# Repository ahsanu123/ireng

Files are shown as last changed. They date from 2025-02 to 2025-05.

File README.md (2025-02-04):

<p>
  <a href="">
    
  </a>
  <a href="">
    
  </a>
  <a href="">
    
  </a>
  <a href="https://github.com/ahsanu123/ireng/blob/main/LICENSE">
    
  </a>
</p>

<p align="center">
   <br/>
</p>

# ✒️ Introduction 

Ireng is custom Black Magic Probe Based on STM32F103RCT. Only for fun 😙 and learning about debugging in microcontroller.

<details>
  <summary>expands me!!</summary>
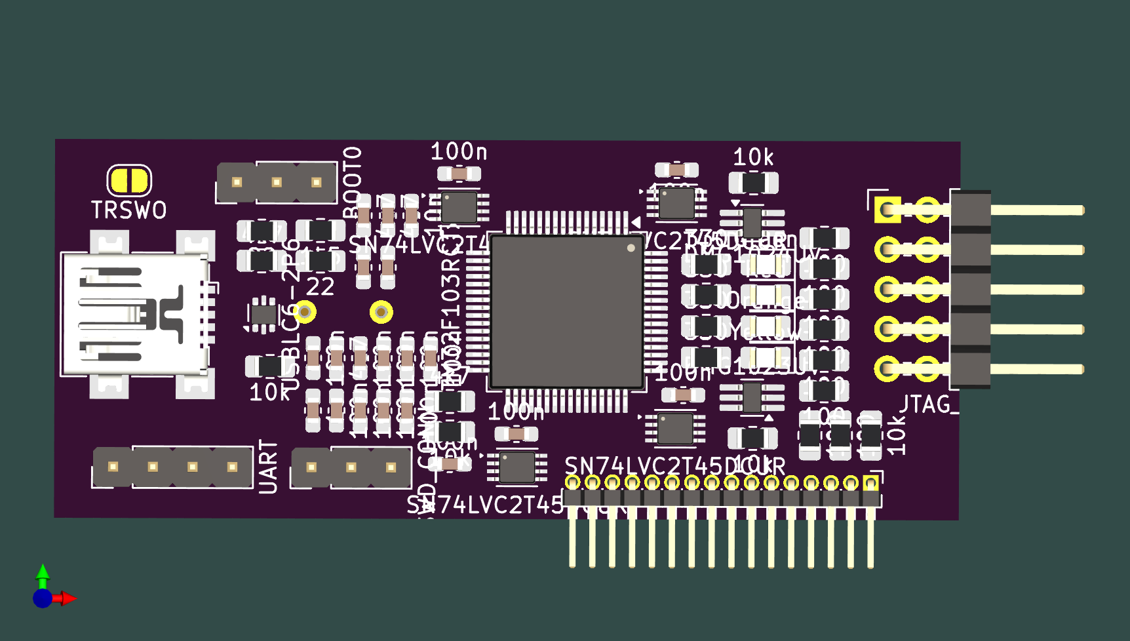
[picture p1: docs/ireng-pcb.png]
     <br/>
</details>

## 🌳 TODO LOG

- ~~Add SPI Flash from windbond, jumat 17 januari 2025 at 19:51~~, no pin left for spi and dont want to change pinout of original schematic.
- ~~re-check schematic,  jumat 17 januari 2025 at 19:51~~
- add usb type c, and use usb micro b as backup,  jumat 17 januari 2025 at 19:51

## 🧱 Reference 

- [Black Magic Probe Book](https://www.compuphase.com/electronics/BlackMagicProbe.pdf)
- [STM32F10xxx Getting Started Hardware Development](https://www.st.com/resource/en/application_note/an2586-getting-started-with-stm32f10xxx-hardware-development-stmicroelectronics.pdf)

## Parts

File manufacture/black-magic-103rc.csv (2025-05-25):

Reference | Value | Datasheet | Footprint | Qty | DNP
C1,C3,C9 | 4u7 | ~ | Capacitor_SMD:C_0603_1608Metric_Pad1.08x0.95mm_HandSolder | 3
C2 | 10n | ~ | Capacitor_SMD:C_0603_1608Metric_Pad1.08x0.95mm_HandSolder | 1
C4,C5,C6,C7,C8,C11,C12,C13,C14,C15,C16,C17,C18,C19,C22 | 100n | ~ | Capacitor_SMD:C_0603_1608Metric_Pad1.08x0.95mm_HandSolder | 15
C10 | 1u | ~ | Capacitor_SMD:C_0603_1608Metric_Pad1.08x0.95mm_HandSolder | 1
C20,C21 | 20p | ~ | Capacitor_SMD:C_0603_1608Metric_Pad1.08x0.95mm_HandSolder | 2
D1 | Green | ~ | LED_SMD:LED_0805_2012Metric_Pad1.15x1.40mm_HandSolder | 1
D2 | Red | ~ | LED_SMD:LED_0805_2012Metric_Pad1.15x1.40mm_HandSolder | 1
D3 | Orange | ~ | LED_SMD:LED_0805_2012Metric_Pad1.15x1.40mm_HandSolder | 1
D4 | Yellow | ~ | LED_SMD:LED_0805_2012Metric_Pad1.15x1.40mm_HandSolder | 1
J1 | USB_B_Micro | ~ | Connector_USB:USB_Mini-B_Wuerth_65100516121_Horizontal | 1
J2 | JTAG_SWD_10 | http://infocenter.arm.com/help/topic/com.arm.doc.ddi0314h/DDI0314H_coresight_components_trm.pdf | Connector_PinHeader_2.54mm:PinHeader_2x05_P2.54mm_Horizontal | 1
J3 | UART | ~ | Connector_PinHeader_2.54mm:PinHeader_1x04_P2.54mm_Vertical | 1
J4 | SWD_CONN | ~ | Connector_PinHeader_2.54mm:PinHeader_1x03_P2.54mm_Vertical | 1
J5 | BOOT0 | ~ | Connector_PinHeader_2.54mm:PinHeader_1x03_P2.54mm_Vertical | 1
J6 | PORTC | ~ | Connector_PinHeader_1.27mm:PinHeader_1x16_P1.27mm_Horizontal | 1
P1 | USB_C_Plug_USB2.0 | https://www.usb.org/sites/default/files/documents/usb_type-c.zip | Connector_USB:USB_C_Receptacle_GCT_USB4110 | 1
Q1 | DMG1024UV | ~ | Package_TO_SOT_SMD:SOT-363_SC-70-6_Handsoldering | 1
Q2 | DMG1023UV | ~ | Package_TO_SOT_SMD:SOT-363_SC-70-6_Handsoldering | 1
R1,R2,R3,R4,R15,R16,R17,R18 | 100 | ~ | Resistor_SMD:R_0805_2012Metric_Pad1.20x1.40mm_HandSolder | 8
R5,R12 | 4k7 | ~ | Resistor_SMD:R_0805_2012Metric_Pad1.20x1.40mm_HandSolder | 2
R6,R7,R8,R13,R14 | 10k | ~ | Resistor_SMD:R_0805_2012Metric_Pad1.20x1.40mm_HandSolder | 5
R9,R10 | 22 | ~ | Resistor_SMD:R_0805_2012Metric_Pad1.20x1.40mm_HandSolder | 2
R11 | 1k5 | ~ | Resistor_SMD:R_0805_2012Metric_Pad1.20x1.40mm_HandSolder | 1
R19,R20,R21,R22 | 330 | ~ | Resistor_SMD:R_0805_2012Metric_Pad1.20x1.40mm_HandSolder | 4
R23,R24 | 5k1 | ~ | Resistor_SMD:R_0805_2012Metric_Pad1.20x1.40mm_HandSolder | 2
SW1 | SW_SPST | ~ | Button_Switch_SMD:SW_Push_1P1T_NO_6x6mm_H9.5mm | 1
U1 | USBLC6-2P6 | https://www.st.com/resource/en/datasheet/usblc6-2.pdf | Package_TO_SOT_SMD:SOT-666 | 1
U2,U5,U6,U7 | SN74LVC2T45DCUR | http://www.ti.com/lit/ds/symlink/sn74lvc2t45.pdf | Package_SO:VSSOP-8_2.4x2.1mm_P0.5mm | 4
U3 | STM32F103RCTx | https://www.st.com/resource/en/datasheet/stm32f103rc.pdf | Package_QFP:LQFP-64_10x10mm_P0.5mm | 1
U4 | AMS1117-3.3 | http://www.advanced-monolithic.com/pdf/ds1117.pdf | Package_TO_SOT_SMD:SOT-223-3_TabPin2 | 1
Y2 | 8Mhz | ~ | Crystal:Crystal_HC18-U_Vertical | 1

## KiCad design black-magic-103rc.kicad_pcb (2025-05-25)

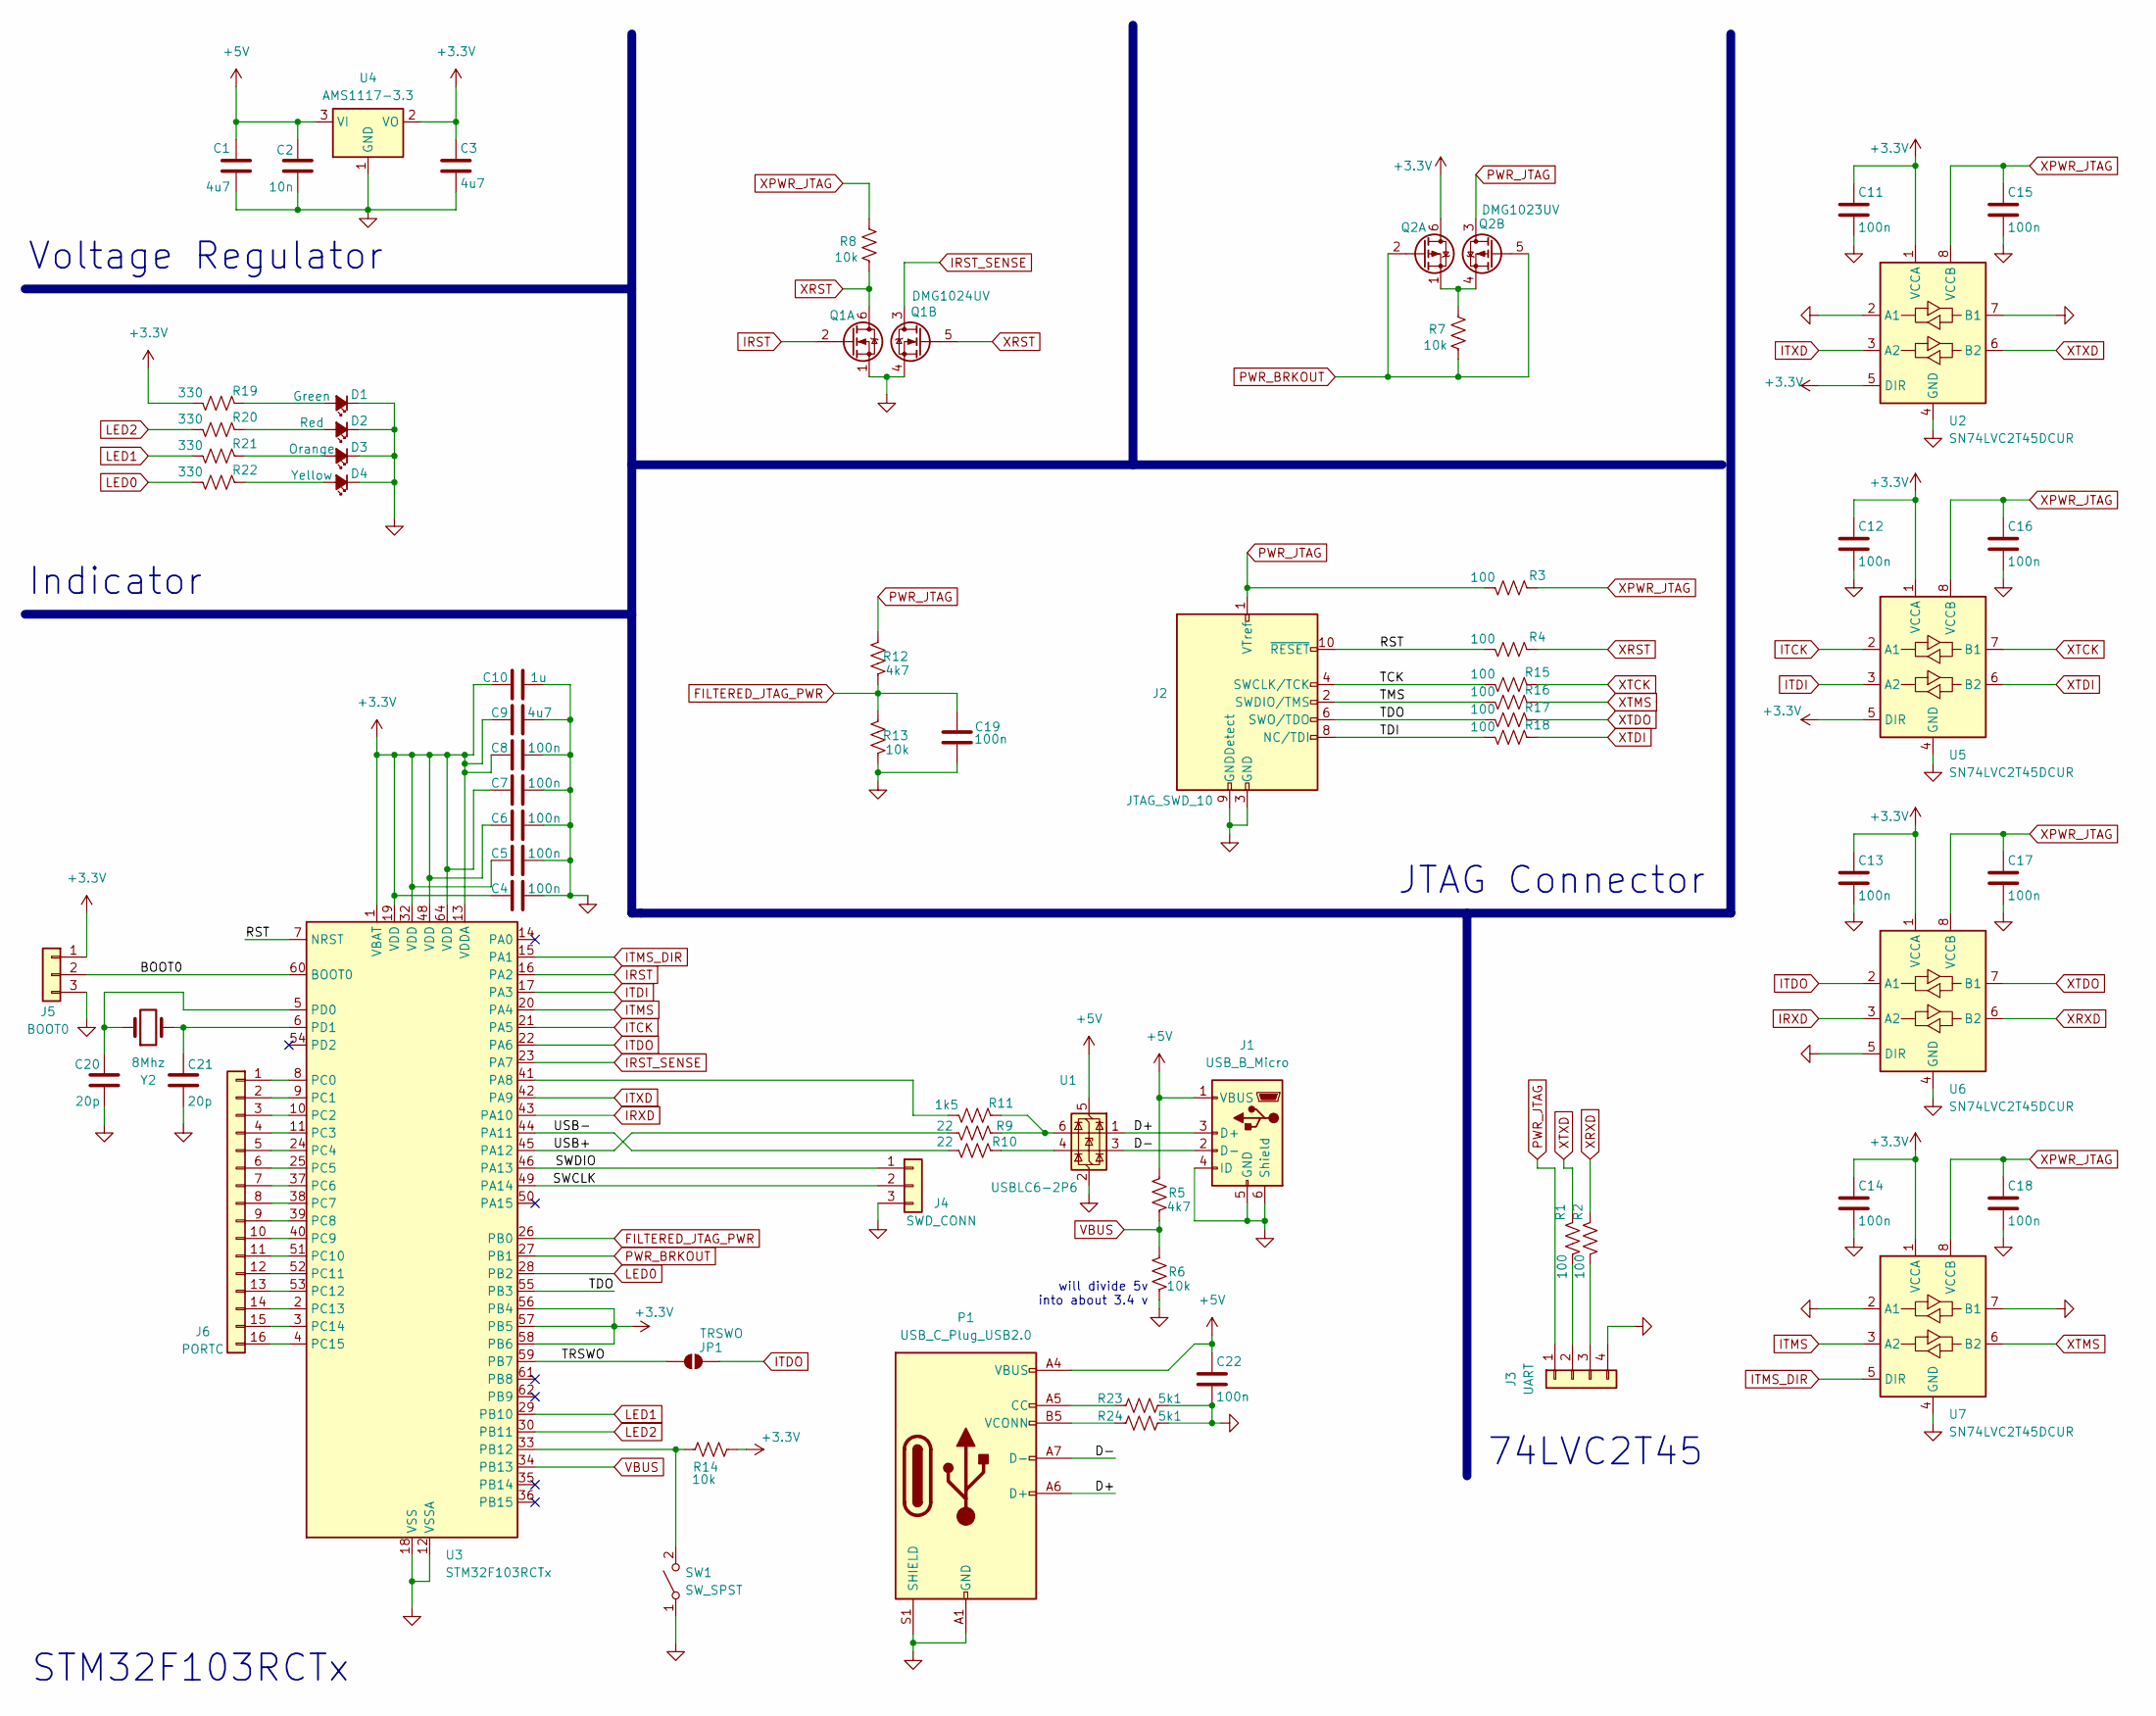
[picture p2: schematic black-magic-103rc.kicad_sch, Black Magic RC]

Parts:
C1, C3, C9: 4u7; C_0603_1608Metric_Pad1.08x0.95mm_HandSolder
C2: 10n; C_0603_1608Metric_Pad1.08x0.95mm_HandSolder
C4, C5, C6, C7, C8, C11, C12, C13, C14, C15, C16, C17, C18, C19, C22: 100n; C_0603_1608Metric_Pad1.08x0.95mm_HandSolder
C10: 1u; C_0603_1608Metric_Pad1.08x0.95mm_HandSolder
C20, C21: 20p; C_0603_1608Metric_Pad1.08x0.95mm_HandSolder
D1: Green; LED_0805_2012Metric_Pad1.15x1.40mm_HandSolder
D2: Red; LED_0805_2012Metric_Pad1.15x1.40mm_HandSolder
D3: Orange; LED_0805_2012Metric_Pad1.15x1.40mm_HandSolder
D4: Yellow; LED_0805_2012Metric_Pad1.15x1.40mm_HandSolder
J1: USB_B_Micro; USB_Mini-B_Wuerth_65100516121_Horizontal
J2: JTAG_SWD_10; PinHeader_2x05_P2.54mm_Horizontal
J3: UART; PinHeader_1x04_P2.54mm_Vertical
J4: SWD_CONN; PinHeader_1x03_P2.54mm_Vertical
J5: BOOT0; PinHeader_1x03_P2.54mm_Vertical
J6: PORTC; PinHeader_1x16_P1.27mm_Horizontal
JP1: TRSWO; SolderJumper-2_P1.3mm_Open_RoundedPad1.0x1.5mm
P1: USB_C_Plug_USB2.0; USB_C_Receptacle_GCT_USB4110
Q1: DMG1024UV; SOT-563
Q2: DMG1023UV; SOT-563
R1, R2, R3, R4, R15, R16, R17, R18: 100; R_0805_2012Metric_Pad1.20x1.40mm_HandSolder
R5, R12: 4k7; R_0805_2012Metric_Pad1.20x1.40mm_HandSolder
R6, R7, R8, R13, R14: 10k; R_0805_2012Metric_Pad1.20x1.40mm_HandSolder
R9, R10: 22; R_0805_2012Metric_Pad1.20x1.40mm_HandSolder
R11: 1k5; R_0805_2012Metric_Pad1.20x1.40mm_HandSolder
R19, R20, R21, R22: 330; R_0805_2012Metric_Pad1.20x1.40mm_HandSolder
R23, R24: 5k1; R_0805_2012Metric_Pad1.20x1.40mm_HandSolder
SW1: SW_SPST; SW_Push_1P1T_NO_6x6mm_H9.5mm
U1: USBLC6-2P6; SOT-666
U2, U5, U6, U7: SN74LVC2T45DCUR; VSSOP-8_2.4x2.1mm_P0.5mm
U3: STM32F103RCTx; LQFP-64_10x10mm_P0.5mm
U4: AMS1117-3.3; SOT-223-3_TabPin2
Y2: 8Mhz; Crystal_HC18-U_Vertical

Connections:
+3.3V: C3.1, C4.1, C5.1, C6.1, C7.1, C8.1, C9.1, C10.1, C11.1, C12.1, C13.1, C14.1, J5.1, Q2.6 (D), R14.1, R19.2, U2.1 (VCCA), U2.5 (DIR), U3.1 (VBAT), U3.13 (VDDA), U3.19 (VDD), U3.32 (VDD), U3.48 (VDD), U3.56 (PB4), U3.57 (PB5), U3.58 (PB6), U3.64 (VDD), U4.2 (VO), U5.1 (VCCA), U5.5 (DIR), U6.1 (VCCA), U7.1 (VCCA)
+5V: C1.1, C2.1, C22.1, J1.1 (VBUS), P1.A4 (VBUS), P1.A9 (VBUS), P1.B4 (VBUS), P1.B9 (VBUS), R5.2, U1.5 (VBUS), U4.3 (VI)
/BOOT0: J5.2, U3.60 (BOOT0)
/D+: J1.3 (D+), P1.A6 (D+), U1.1 (I/O1)
/D-: J1.2 (D-), P1.A7 (D-), U1.3 (I/O2)
/RST: J2.10 (~RESET), R4.2, U3.7 (NRST)
/SWCLK: J4.2, U3.49 (PA14)
/SWDIO: J4.1, U3.46 (PA13)
/TCK: J2.4 (SWCLK/TCK), R15.2
/TDI: J2.8 (NC/TDI), R18.2
/TDO: J2.6 (SWO/TDO), R17.2, U3.55 (PB3)
/TMS: J2.2 (SWDIO/TMS), R16.2
/TRSWO: JP1.1 (A), U3.59 (PB7)
/USB+: R9.2, U3.45 (PA12)
/USB-: R10.2, U3.44 (PA11)
FILTERED_JTAG_PWR: C19.1, R12.1, R13.2, U3.26 (PB0)
GND: C1.2, C2.2, C3.2, C4.2, C5.2, C6.2, C7.2, C8.2, C9.2, C10.2, C11.2, C12.2, C13.2, C14.2, C15.2, C16.2, C17.2, C18.2, C19.2, C20.2, C21.2, C22.2, D1.1 (K), D2.1 (K), D3.1 (K), D4.1 (K), J1.4 (ID), J1.5 (GND), J1.6 (Shield), J2.3 (GND), J2.5 (GND), J2.9 (GNDDetect), J3.4, J4.3, J5.3, P1.A1 (GND), P1.A12 (GND), P1.B1 (GND), P1.B12 (GND), P1.S1 (SHIELD), Q1.1 (S), Q1.4 (S), R6.1, R13.1, R23.1, R24.1, SW1.1 (A), U1.2 (GND), U2.2 (A1), U2.4 (GND), U2.7 (B1), U3.12 (VSSA), U3.18 (VSS), U3.31 (VSS), U3.47 (VSS), U3.63 (VSS), U4.1 (GND), U5.4 (GND), U6.4 (GND), U6.5 (DIR), U7.2 (A1), U7.4 (GND), U7.7 (B1)
IRST: Q1.2 (G), U3.16 (PA2)
IRST_SENSE: Q1.3 (D), U3.23 (PA7)
IRXD: U3.43 (PA10), U6.3 (A2)
ITCK: U3.21 (PA5), U5.2 (A1)
ITDI: U3.17 (PA3), U5.3 (A2)
ITDO: JP1.2 (B), U3.22 (PA6), U6.2 (A1)
ITMS: U3.20 (PA4), U7.3 (A2)
ITMS_DIR: U3.15 (PA1), U7.5 (DIR)
ITXD: U2.3 (A2), U3.42 (PA9)
LED0: R22.2, U3.28 (PB2)
LED1: R21.2, U3.29 (PB10)
LED2: R20.2, U3.30 (PB11)
unnamed: D1.2 (A), R19.1
unnamed: D2.2 (A), R20.1
unnamed: D3.2 (A), R21.1
unnamed: D4.2 (A), R22.1
unnamed: J3.2, R1.2
unnamed: J3.3, R2.2
unnamed: J6.1, U3.8 (PC0)
unnamed: J6.2, U3.9 (PC1)
unnamed: J6.3, U3.10 (PC2)
unnamed: J6.4, U3.11 (PC3)
unnamed: J6.5, U3.24 (PC4)
unnamed: J6.6, U3.25 (PC5)
unnamed: J6.7, U3.37 (PC6)
unnamed: J6.8, U3.38 (PC7)
unnamed: J6.9, U3.39 (PC8)
unnamed: J6.10, U3.40 (PC9)
unnamed: J6.11, U3.51 (PC10)
unnamed: J6.12, U3.52 (PC11)
unnamed: J6.13, U3.53 (PC12)
unnamed: J6.14, U3.2 (PC13)
unnamed: J6.15, U3.3 (PC14)
unnamed: J6.16, U3.4 (PC15)
unnamed: P1.A5 (CC), R23.2
unnamed: P1.B5 (VCONN), R24.2
unnamed: Q2.1 (S), Q2.4 (S), R7.2
unnamed: R10.1, U1.4 (I/O2)
unnamed: R9.1, R11.1, U1.6 (I/O1)
unnamed: R14.2, SW1.2 (B), U3.33 (PB12)
unnamed: R11.2, U3.41 (PA8)
unnamed: C20.1, U3.5 (PD0), Y2.1
unnamed: C21.1, U3.6 (PD1), Y2.2
PWR_BRKOUT: Q2.2 (G), Q2.5 (G), R7.1, U3.27 (PB1)
PWR_JTAG: J2.1 (VTref), J3.1, Q2.3 (D), R3.2, R12.2
VBUS: R5.1, R6.2, U3.34 (PB13)
XPWR_JTAG: C15.1, C16.1, C17.1, C18.1, R3.1, R8.2, U2.8 (VCCB), U5.8 (VCCB), U6.8 (VCCB), U7.8 (VCCB)
XRST: Q1.5 (G), Q1.6 (D), R4.1, R8.1
XRXD: R2.1, U6.6 (B2)
XTCK: R15.1, U5.7 (B1)
XTDI: R18.1, U5.6 (B2)
XTDO: R17.1, U6.7 (B1)
XTMS: R16.1, U7.6 (B2)
XTXD: R1.1, U2.6 (B2)

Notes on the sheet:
74LVC2T45
JTAG Connector
Voltage Regulator
Indicator
STM32F103RCTx
will divide 5v into about 3.4 v

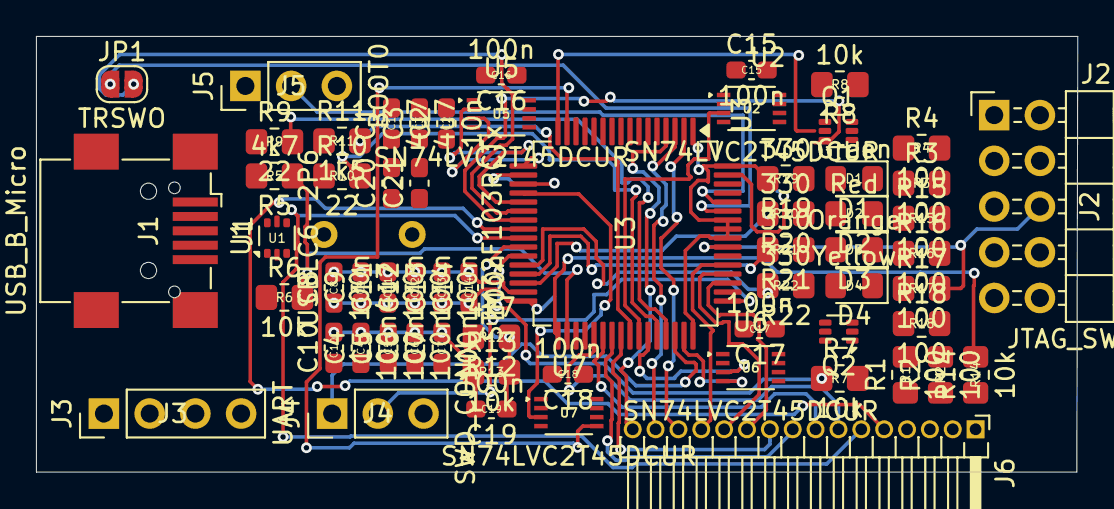
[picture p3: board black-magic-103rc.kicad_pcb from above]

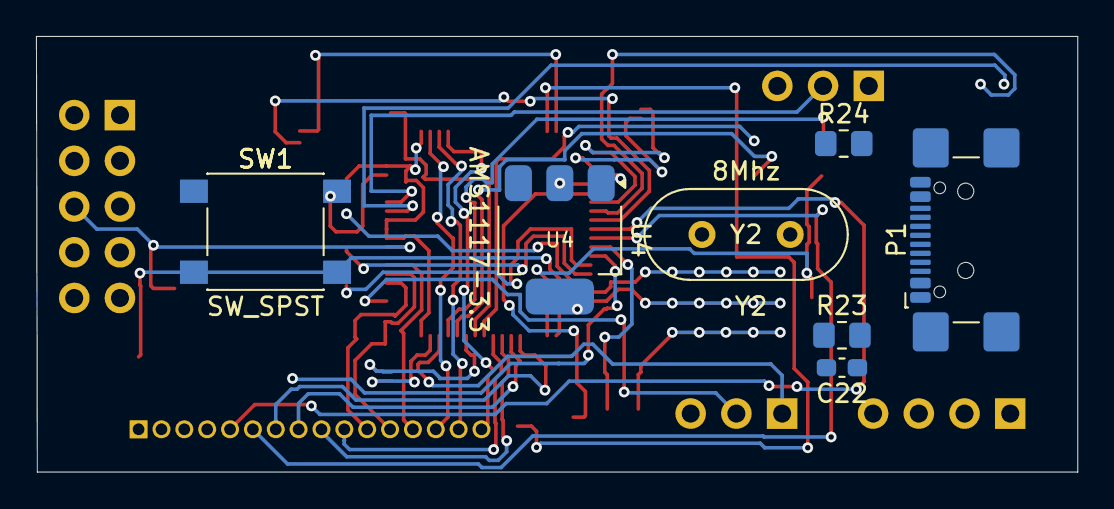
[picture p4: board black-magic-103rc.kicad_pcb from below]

Board: 2 copper layers, 57.9 x 24.2 mm, 69 parts (7 on the bottom side), 71 nets.

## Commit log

2025-01-17 [01-17-1811] moved black magic probe to new ireng repository
    [black-magic-103rc.kicad_pcb, black-magic-103rc.kicad_sch]
2025-01-17 [01-17-1939] copied schematic from reference, need to re-confirm
    Update README.md
    [black-magic-103rc.kicad_sch]
2025-01-19 [01-19-2111] finish basic board component placement
    nit
    [black-magic-103rc.kicad_pcb, black-magic-103rc.kicad_sch]
2025-02-04 [02-04-1948] start to routing
    [black-magic-103rc.kicad_pcb, black-magic-103rc.kicad_sch]
2025-05-25 [05-25-1348] generate bom
    [black-magic-103rc.csv, black-magic-103rc.kicad_pcb, black-magic-103rc.kicad_sch]
